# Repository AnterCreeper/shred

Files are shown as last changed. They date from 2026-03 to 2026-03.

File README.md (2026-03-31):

# SHRED: (S)ystem for (H)igh-performance (R)eal-time (E)lectric guitar (D)igital effects

If you have any questions, feel free to open Issues & PRs.

**WARNING! This project has not been fully tested in long-term production environments and is provided without warranty of any kind. Use at your own risk!**

## License

This project is licensed under the LGPL-2.1-or-later license.

**DO NOT** download or clone this project until you have read and agreed to the LICENSE.

## TODO

1. plug subboard designs
2. FPGA RTL integration
3. controller firmware

## Overview

This project implements an audio system for electric guitars and consists of essential components, including the hardware (core and plug) with Gerber files and schematics, digital logic designs, mechanical designs for the pickguard, and firmware for a low-power microcontroller that provides HMI and system controls.

The TFT screen is not included, which is from Waveshare ([Click here](https://www.waveshare.net/wiki/1.9inch_LCD_Module)) and would be easy to obtain.

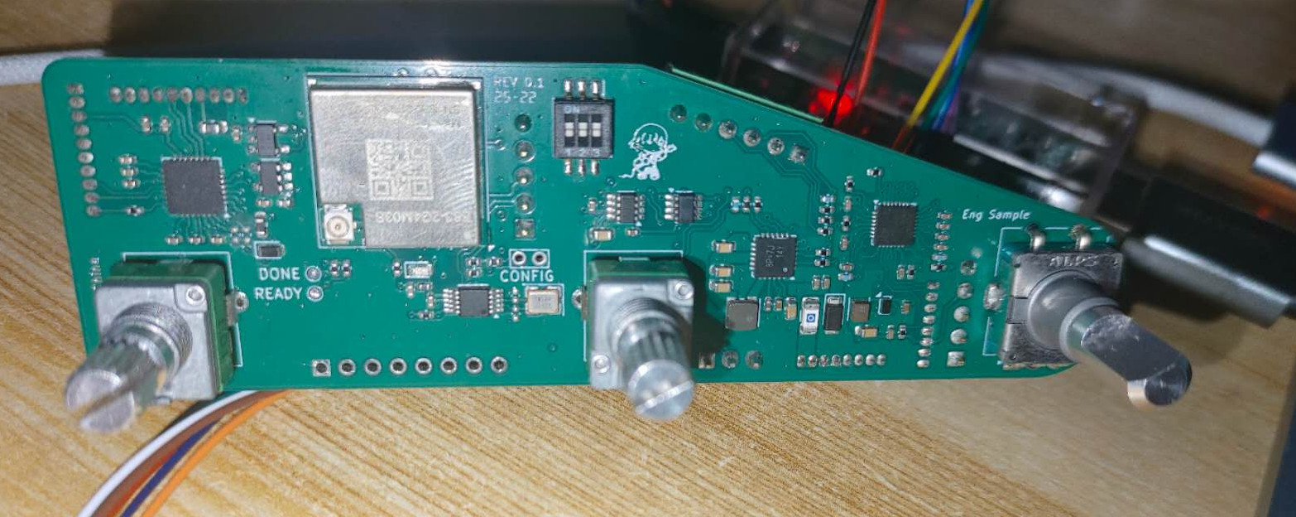
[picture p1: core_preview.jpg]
PCB Preview Picture


## Functions

- Audio Record & Playback (SD Card)
- Audio Mixer
- USB Audio Input and Output
- Wireless BLE Real-time Audio Monitor
- Audio Effects (chorus, distortion, EQ...)

## Directory

### Core

This directory contains PCB designs (KiCad) for the main board, which implements most functions. It includes battery management (TI `BQ25601` charger with `TPD2S300` for Type-C PD high-voltage fast charging, and TI `BQ27720` energy gauge), system microcontroller (WCH `CH32X035`), FPGA unit (Gowin `Tang Primer 25K`), and the audio subsystem (ADI/Maxim `MAX9850` I2S DAC + onsemi `FAN3852` AFE+ADC to PDM, and Skyworks/Silicon Labs `Si5351` for clock generation). In addition, this system includes a BLE module (Nordic `nRF5340`) to provide ultra-low latency LE Audio streaming capability.

The power rails are carefully designed to provide long battery life. The system employs several load switches (MPS `MP5095` and Diodes `AP2151`) and ultra-low quiescent current regulators (TI `TPS62743` and `TPS7A20`), allowing specific components (keys and screen, audio system, flash storage, Bluetooth) to be shut down or set to low-power states.

The dual magnetic pickups are connected via IPEX-4 (some soldering work is required to modify the connection wires), which provides low-noise, pure raw signals.

### Plug

This directory contains PCB designs (KiCad) for the plug subboard, which includes an `audio jack`, `microSD slot`, `USB-C receptacle`, `charge indicator`, and `ambient light sensor`.

### RTL

This directory contains the audio processing logic:
- Core processor
- Audio synthesizer
- FLAC encoder & decoder
- Audio I/O interface
- USB device interface
- I2C device interface
- SD host controller interface

### Controller

This directory contains the system controller firmware, which sets up every device, monitors system states, renders the HMI, and reacts to user input events.

### LE-Audio

This directory contains the BLE module firmware subproject from a separate repository. It scans, connects, and pairs with earbuds, and then performs real-time audio streaming (LC3). This module acts as a peripheral to the system controller, communicating via a standard AT interface over UART.

### Others

Miscellaneous files under the root:
- `pickguard.dxf`: Pickguard CAD designs.
- `logo.jped`: Logo of `SHRED`, generated by Google NanoBanana 2.
- `logo.prompt`: Prompt of AI gen.

## Usage

**This section is W.I.P. and will be completed in the future.**

Star History Chart (https://www.star-history.com/#antercreeper/shred&type=date&legend=top-left)

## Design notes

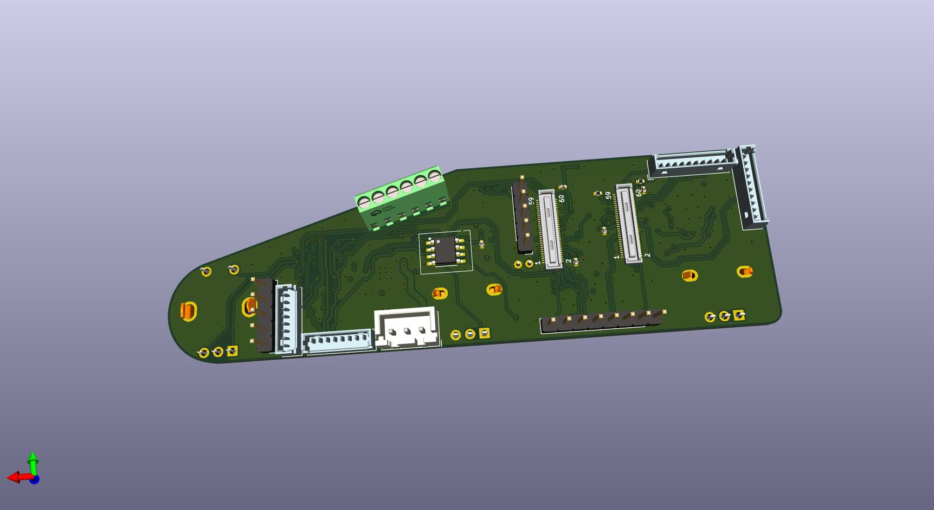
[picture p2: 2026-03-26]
core/audio_lab_back.jpg

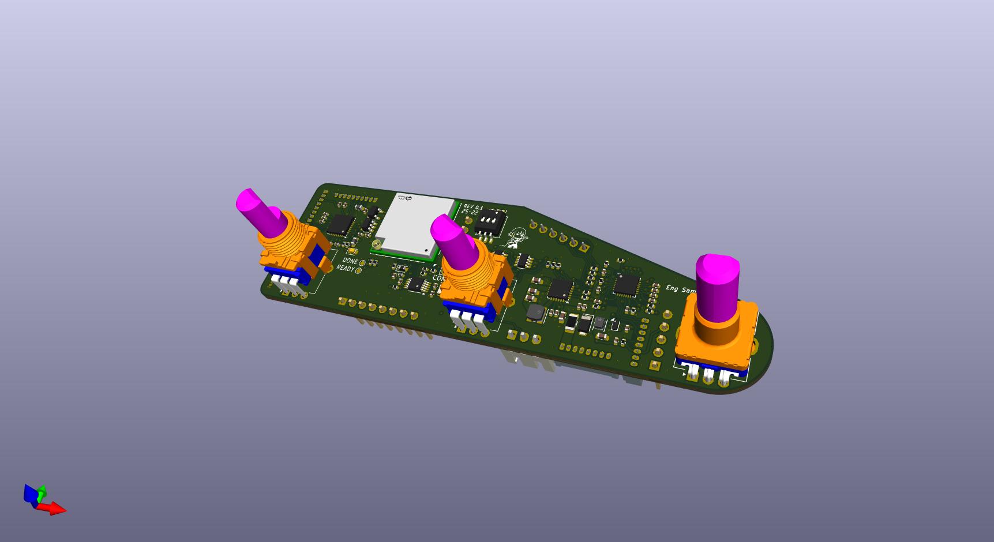
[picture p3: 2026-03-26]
core/audio_lab_front.jpg

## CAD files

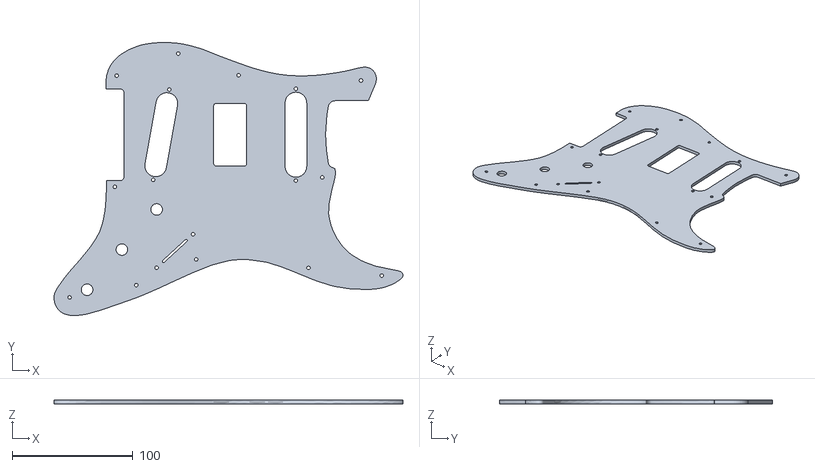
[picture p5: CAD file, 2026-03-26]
pickguard.stl
289.1 x 226.3 x 3.00

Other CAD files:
pickguard.dxf

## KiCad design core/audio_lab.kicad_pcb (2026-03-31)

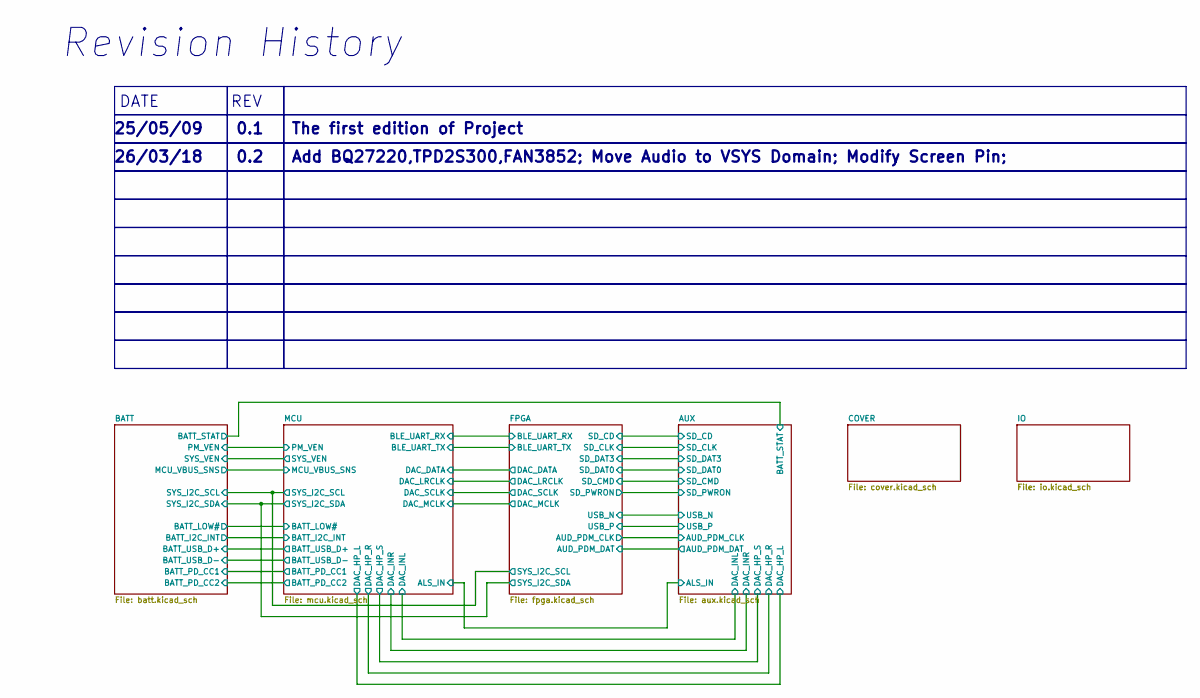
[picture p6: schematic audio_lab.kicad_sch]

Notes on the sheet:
Revision History
REV
0.2
Add BQ27220,TPD2S300,FAN3852; Move Audio to VSYS Domain; Modify Screen Pin;
0.1
25/05/09
The first edition of Project
DATE
26/03/18

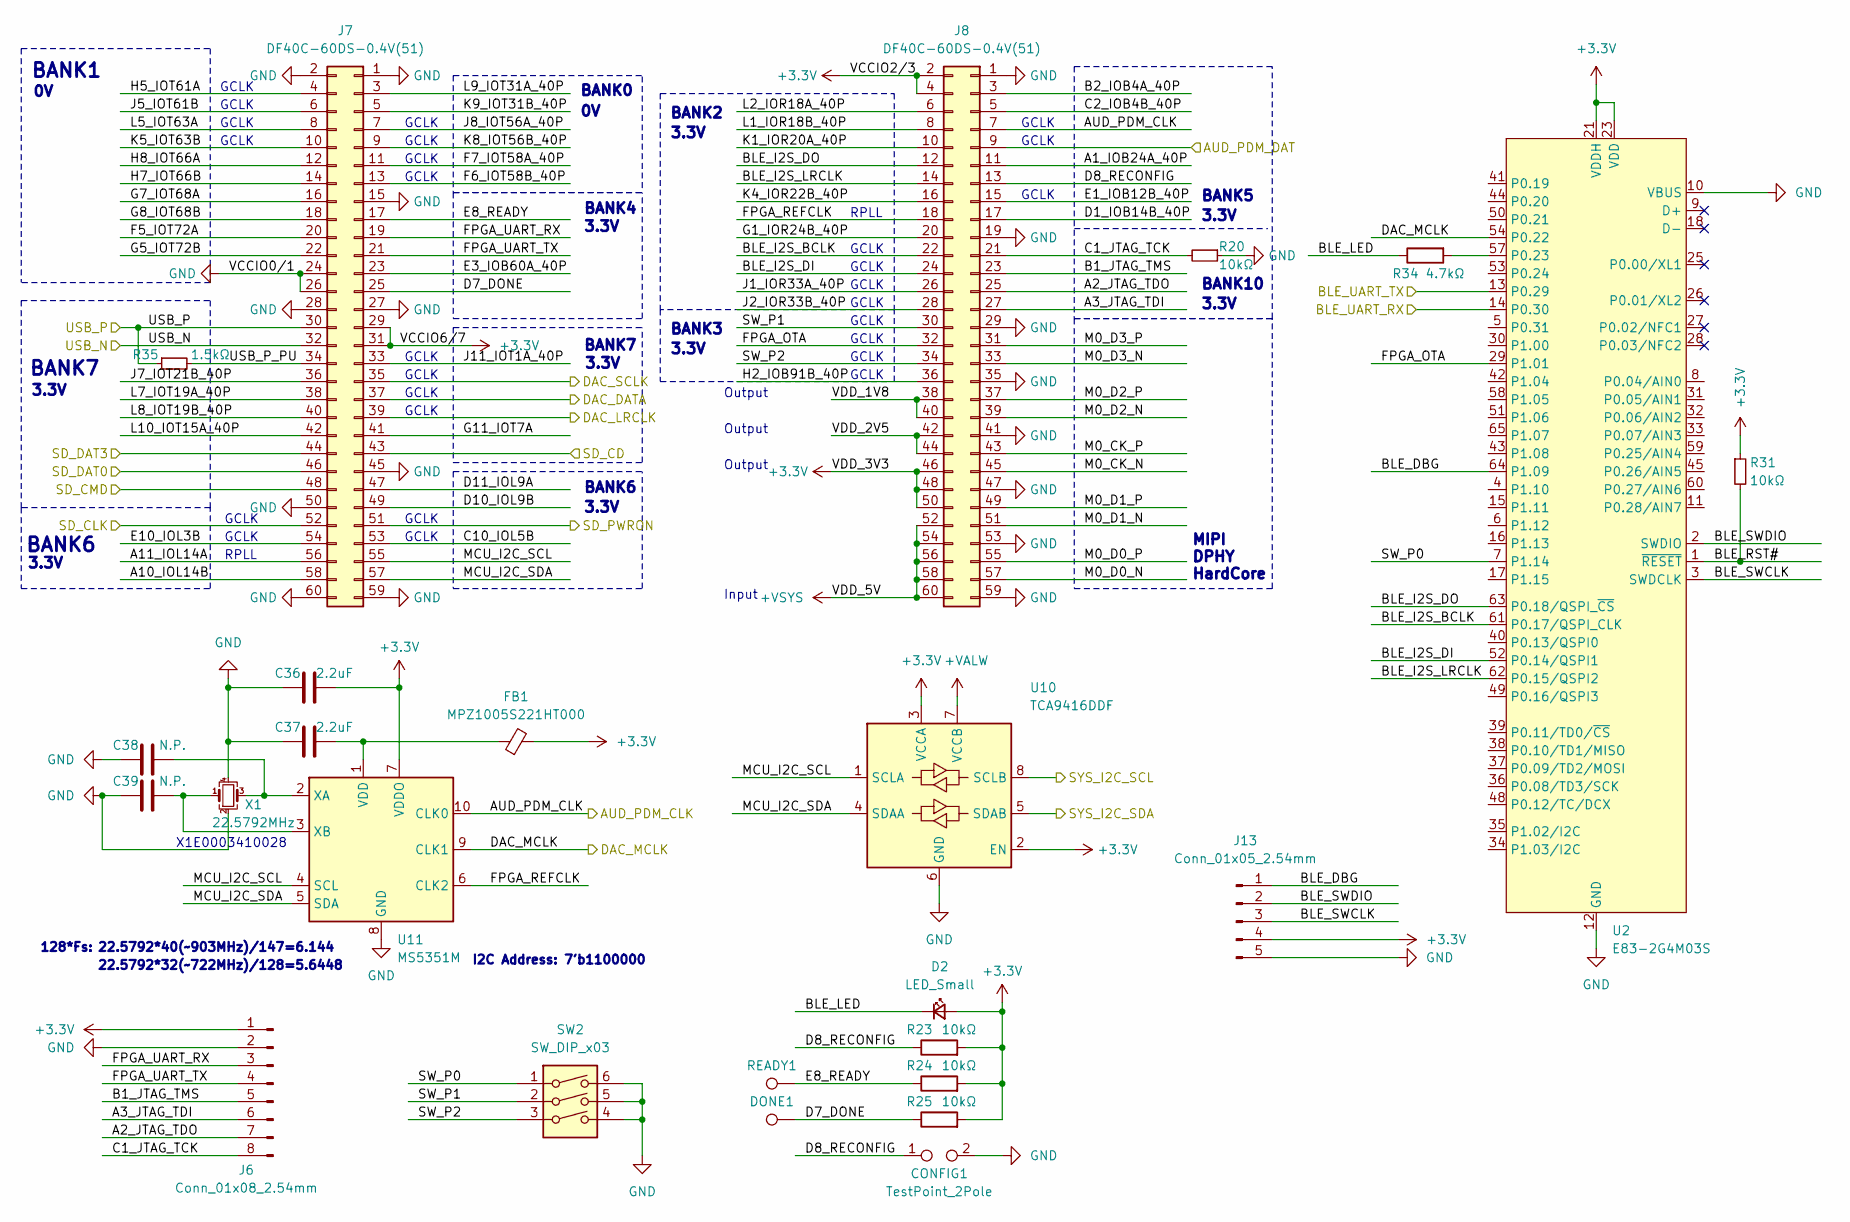
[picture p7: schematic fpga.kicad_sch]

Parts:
C36, C37: 2.2uF; C_0402_1005Metric
C38, C39: N.P.; C_0402_1005Metric
CONFIG1: TestPoint_2Pole; TestPoint_Bridge_Pitch2.0mm_Drill0.7mm
D2: LED_Small; D_0603_1608Metric
DONE1: TestPoint; TestPoint_Pad_D1.0mm
FB1: MPZ1005S221HT000; L_0402_1005Metric
J6: Conn_01x08_2.54mm; PinHeader_1x08_P2.54mm_Vertical
J7, J8: DF40C-60DS-0.4V(51); BTB-DF40C-60DS-0.4V(51)
J13: Conn_01x05_2.54mm; PinHeader_1x05_P2.54mm_Vertical
R20, R23, R24, R25, R31: 10kΩ; R_0402_1005Metric
R34: 4.7kΩ; R_0402_1005Metric
R35: 1.5kΩ; R_0402_1005Metric
READY1: TestPoint; TestPoint_Pad_D1.0mm
SW2: SW_DIP_x03; SW_DIP_SPSTx03_Slide_KingTek_DSHP03TS_W7.62mm_P1.27mm
U2: E83-2G4M03S; E83-2G4M03S_16x16mm_LGA; LCSC C5333991
U10: TCA9416DDF; TSOT-23-8
U11: MS5351M; MSOP-10_3x3mm_P0.5mm
X1: 22.5792MHz; Crystal_SMD_3225-4Pin_3.2x2.5mm

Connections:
+3.3V: C36.2, D2.2 (A), FB1.2, J6.1, J7.29, J7.31, J8.2, J8.4, J8.46, J8.48, J8.50, J13.4, R23.2, R24.2, R25.2, R31.1, U2.21 (VDDH), U2.23 (VDD), U10.2 (EN), U10.3 (VCCA), U11.7 (VDDO); also elsewhere on the board
+VALW: U10.7 (VCCB); also elsewhere on the board
+VSYS: J8.52, J8.54, J8.56, J8.58, J8.60; also elsewhere on the board
/AUX/AUD_PDM_DAT: J8.9; also elsewhere on the board
/AUX/SD_CD: J7.43; also elsewhere on the board
/AUX/SD_CLK: J7.52; also elsewhere on the board
/AUX/SD_CMD: J7.48; also elsewhere on the board
/AUX/SD_DAT0: J7.46; also elsewhere on the board
/AUX/SD_DAT3: J7.44; also elsewhere on the board
/AUX/SD_PWRON: J7.51; also elsewhere on the board
/BATT/SYS_I2C_SCL: U10.8 (SCLB); also elsewhere on the board
/BATT/SYS_I2C_SDA: U10.5 (SDAB); also elsewhere on the board
/FPGA/A1_IOB24A_40P: J8.11
/FPGA/A2_JTAG_TDO: J6.7, J8.25
/FPGA/A3_JTAG_TDI: J6.6, J8.27
/FPGA/A10_IOL14B: J7.58
/FPGA/A11_IOL14A: J7.56
/FPGA/AUD_PDM_CLK: J8.7, U11.10 (CLK0); also elsewhere on the board
/FPGA/B1_JTAG_TMS: J6.5, J8.23
/FPGA/B2_IOB4A_40P: J8.3
/FPGA/BLE_DBG: J13.1, U2.64 (P1.09)
/FPGA/BLE_I2S_BCLK: J8.22, U2.61 (P0.17/QSPI_CLK)
/FPGA/BLE_I2S_DI: J8.24, U2.52 (P0.14/QSPI1)
/FPGA/BLE_I2S_DO: J8.12, U2.63 (P0.18/QSPI_~CS)
/FPGA/BLE_I2S_LRCLK: J8.14, U2.62 (P0.15/QSPI2)
/FPGA/BLE_LED: D2.1 (K), R34.1
/FPGA/BLE_RST#: R31.2, U2.1 (~RESET)
/FPGA/BLE_SWCLK: J13.3, U2.3 (SWDCLK)
/FPGA/BLE_SWDIO: J13.2, U2.2 (SWDIO)
/FPGA/BLE_UART_RX: U2.14 (P0.30); also elsewhere on the board
/FPGA/BLE_UART_TX: U2.13 (P0.29); also elsewhere on the board
/FPGA/C1_JTAG_TCK: J6.8, J8.21, R20.2
/FPGA/C2_IOB4B_40P: J8.5
/FPGA/C10_IOL5B: J7.53
/FPGA/D1_IOB14B_40P: J8.17
/FPGA/D7_DONE: DONE1.1, J7.25, R25.1; also elsewhere on the board
/FPGA/D8_RECONFIG: CONFIG1.1, J8.13, R23.1; also elsewhere on the board
/FPGA/D10_IOL9B: J7.49
/FPGA/D11_IOL9A: J7.47
/FPGA/DAC_DATA: J7.37; also elsewhere on the board
/FPGA/DAC_LRCLK: J7.39; also elsewhere on the board
/FPGA/DAC_MCLK: U2.54 (P0.22), U11.9 (CLK1); also elsewhere on the board
/FPGA/DAC_SCLK: J7.35; also elsewhere on the board
/FPGA/E1_IOB12B_40P: J8.15
/FPGA/E3_IOB60A_40P: J7.23
/FPGA/E8_READY: J7.17, R24.1, READY1.1; also elsewhere on the board
/FPGA/E10_IOL3B: J7.54
/FPGA/F5_IOT72A: J7.20
/FPGA/F6_IOT58B_40P: J7.13
/FPGA/F7_IOT58A_40P: J7.11
/FPGA/FPGA_OTA: J8.32, U2.29 (P1.01)
/FPGA/FPGA_REFCLK: J8.18, U11.6 (CLK2)
/FPGA/FPGA_UART_RX: J6.3, J7.19
/FPGA/FPGA_UART_TX: J6.4, J7.21
/FPGA/G1_IOR24B_40P: J8.20
/FPGA/G5_IOT72B: J7.22
/FPGA/G7_IOT68A: J7.16
/FPGA/G8_IOT68B: J7.18
/FPGA/G11_IOT7A: J7.41
/FPGA/H2_IOB91B_40P: J8.36
/FPGA/H5_IOT61A: J7.4
/FPGA/H7_IOT66B: J7.14
/FPGA/H8_IOT66A: J7.12
/FPGA/J1_IOR33A_40P: J8.26
/FPGA/J2_IOR33B_40P: J8.28
/FPGA/J5_IOT61B: J7.6
/FPGA/J7_IOT21B_40P: J7.36
/FPGA/J8_IOT56A_40P: J7.7
/FPGA/J11_IOT1A_40P: J7.33
/FPGA/K1_IOR20A_40P: J8.10
/FPGA/K4_IOR22B_40P: J8.16
/FPGA/K5_IOT63B: J7.10
/FPGA/K8_IOT56B_40P: J7.9
/FPGA/K9_IOT31B_40P: J7.5
/FPGA/L1_IOR18B_40P: J8.8
/FPGA/L2_IOR18A_40P: J8.6
/FPGA/L5_IOT63A: J7.8
/FPGA/L7_IOT19A_40P: J7.38
/FPGA/L8_IOT19B_40P: J7.40
/FPGA/L9_IOT31A_40P: J7.3
/FPGA/L10_IOT15A_40P: J7.42
/FPGA/M0_CK_N: J8.45
/FPGA/M0_CK_P: J8.43
/FPGA/M0_D0_N: J8.57
/FPGA/M0_D0_P: J8.55
/FPGA/M0_D1_N: J8.51
/FPGA/M0_D1_P: J8.49
/FPGA/M0_D2_N: J8.39
/FPGA/M0_D2_P: J8.37
/FPGA/M0_D3_N: J8.33
/FPGA/M0_D3_P: J8.31
/FPGA/MCU_I2C_SCL: J7.55, U10.1 (SCLA), U11.4 (SCL)
/FPGA/MCU_I2C_SDA: J7.57, U10.4 (SDAA), U11.5 (SDA)
/FPGA/SW_P0: SW2.1, U2.7 (P1.14)
/FPGA/SW_P1: J8.30, SW2.2
/FPGA/SW_P2: J8.34, SW2.3
/FPGA/USB_N: J7.32; also elsewhere on the board
/FPGA/USB_P: J7.30, R35.1; also elsewhere on the board
/FPGA/USB_P_PU: J7.34, R35.2
/FPGA/VDD_1V8: J8.38, J8.40
/FPGA/VDD_2V5: J8.42, J8.44
GND: C36.1, C37.1, C38.1, C39.1, CONFIG1.2, J6.2, J7.1, J7.2, J7.15, J7.24, J7.26, J7.27, J7.28, J7.45, J7.50, J7.59, J7.60, J8.1, J8.19, J8.29, J8.35, J8.41, J8.47, J8.53, J8.59, J13.5, R20.1, SW2.4, SW2.5, SW2.6, U2.10 (VBUS), U2.12 (GND), U2.19 (GND), U2.20 (GND), U2.22 (GND), U2.24 (GND), U2.46 (GND), U2.47 (GND), U2.55 (GND), U2.56 (GND), U10.6 (GND), U11.8 (GND), X1.2, X1.4; also elsewhere on the board
unnamed: R34.2, U2.57 (P0.23)
unnamed: C37.2, FB1.1, U11.1 (VDD)
unnamed: C38.2, U11.2 (XA), X1.3
unnamed: C39.2, U11.3 (XB), X1.1

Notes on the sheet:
GCLK
BANK6
RPLL
BANK2
22.5792*32(~722MHz)/128=5.6448
3.3V
BANK10
MIPI DPHY HardCore
BANK4
BANK5
X1E0003410028
Input
Output
BANK7
I2C Address: 7'b1100000
128*Fs:
BANK1
22.5792*40(~903MHz)/147=6.144
BANK3
BANK0

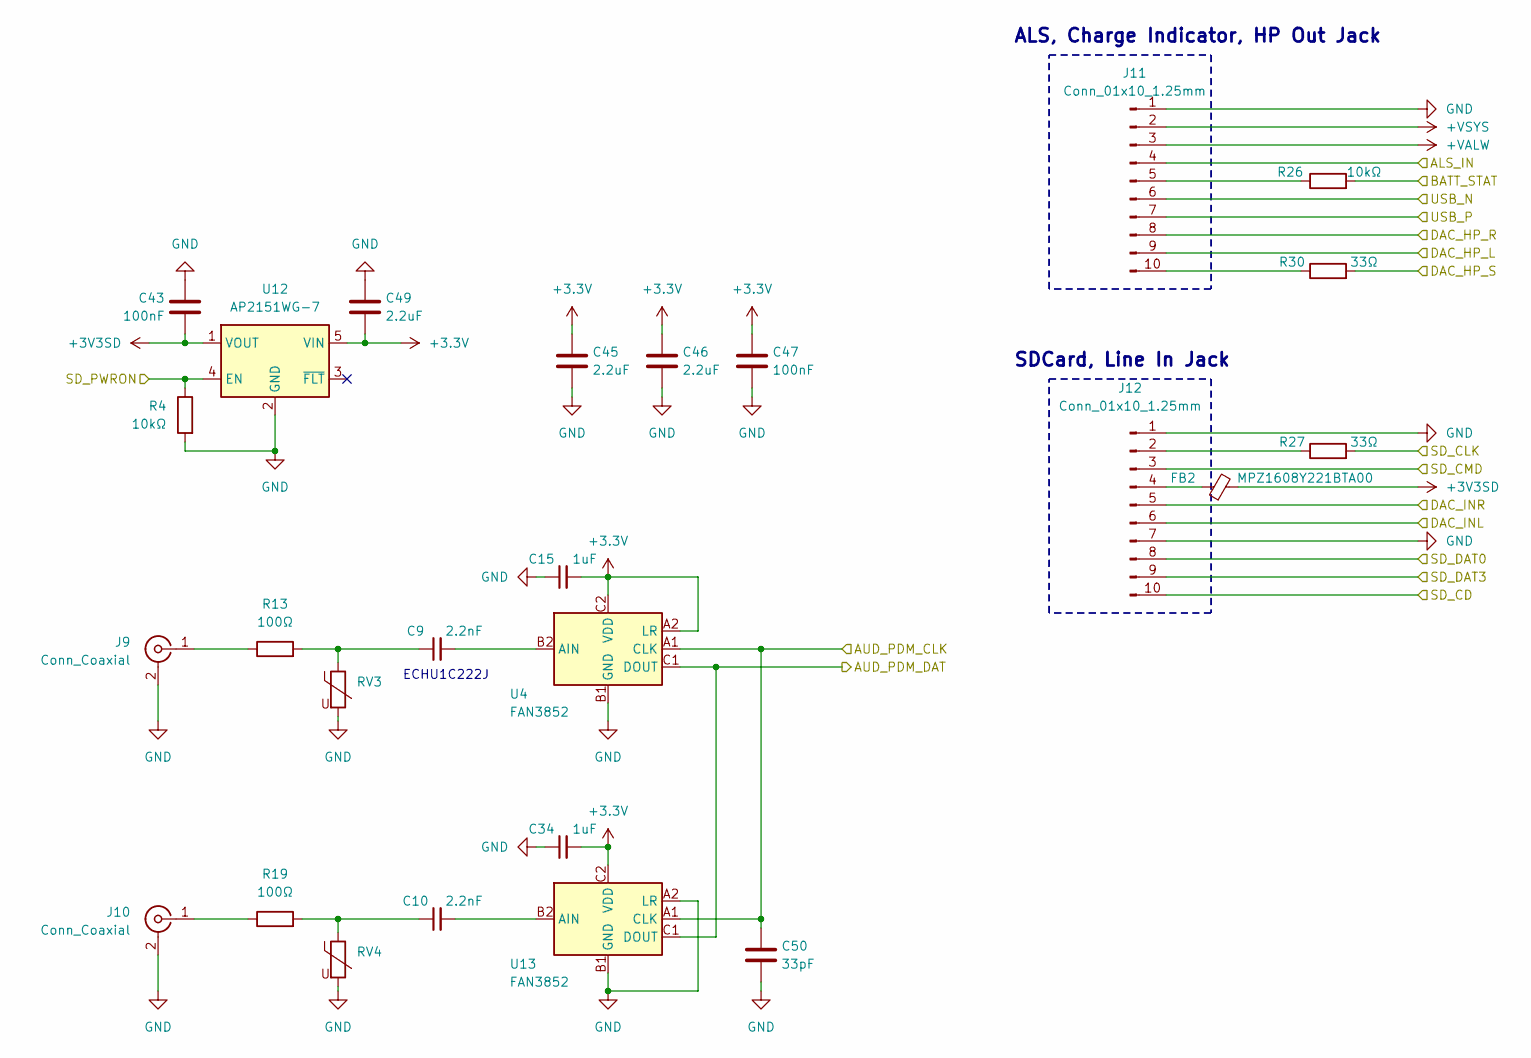
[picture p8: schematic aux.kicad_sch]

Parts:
C9, C10: 2.2nF; C_0603_1608Metric
C15, C34: 1uF; C_0402_1005Metric
C43, C47: 100nF; C_0402_1005Metric
C45, C46, C49: 2.2uF; C_0402_1005Metric
C50: 33pF; C_0402_1005Metric
FB2: MPZ1608Y221BTA00; L_0603_1608Metric
J9, J10: Conn_Coaxial; IPEX_20449-001E-03
J11, J12: Conn_01x10_1.25mm; Molex_PicoBlade_53047-1010_1x10_P1.25mm_Vertical
R4, R26: 10kΩ; R_0402_1005Metric
R13, R19: 100Ω; R_0402_1005Metric
R27, R30: 33Ω; R_0402_1005Metric
RV3, RV4: Varistor; R_0402_1005Metric
U4, U13: FAN3852; Texas_DSBGA-6_0.855x1.255mm_Layout2x3_P0.4mm_LevelC
U12: AP2151WG-7; SOT-23-5

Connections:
+3.3V: C15.2, C34.2, C45.1, C46.1, C47.1, C49.2, U4.A2 (LR), U4.C2 (VDD), U12.5 (VIN), U13.C2 (VDD); also elsewhere on the board
+3V3SD: C43.2, FB2.2, U12.1 (VOUT)
+VALW: J11.3; also elsewhere on the board
+VSYS: J11.2; also elsewhere on the board
/AUX/ALS_IN: J11.4; also elsewhere on the board
/AUX/AUD_PDM_DAT: U4.C1 (DOUT), U13.C1 (DOUT); also elsewhere on the board
/AUX/BATT_STAT: R26.2; also elsewhere on the board
/AUX/DAC_HP_L: J11.9; also elsewhere on the board
/AUX/DAC_HP_R: J11.8; also elsewhere on the board
/AUX/DAC_HP_S: R30.2; also elsewhere on the board
/AUX/DAC_INL: J12.6; also elsewhere on the board
/AUX/DAC_INR: J12.5; also elsewhere on the board
/AUX/SD_CD: J12.10; also elsewhere on the board
/AUX/SD_CLK: R27.2; also elsewhere on the board
/AUX/SD_CMD: J12.3; also elsewhere on the board
/AUX/SD_DAT0: J12.8; also elsewhere on the board
/AUX/SD_DAT3: J12.9; also elsewhere on the board
/AUX/SD_PWRON: R4.1, U12.4 (EN); also elsewhere on the board
/FPGA/AUD_PDM_CLK: C50.1, U4.A1 (CLK), U13.A1 (CLK); also elsewhere on the board
/FPGA/USB_N: J11.6; also elsewhere on the board
/FPGA/USB_P: J11.7; also elsewhere on the board
GND: C15.1, C34.1, C43.1, C45.2, C46.2, C47.2, C49.1, C50.2, J9.2 (Ext), J10.2 (Ext), J11.1, J12.1, J12.7, R4.2, RV3.2, RV4.2, U4.B1 (GND), U12.2 (GND), U13.A2 (LR), U13.B1 (GND); also elsewhere on the board
unnamed: C9.1, R13.2, RV3.1
unnamed: C10.1, R19.2, RV4.1
unnamed: J9.1 (In), R13.1
unnamed: J10.1 (In), R19.1
unnamed: J11.5, R26.1
unnamed: J11.10, R30.1
unnamed: J12.2, R27.1
unnamed: FB2.1, J12.4
unnamed: C9.2, U4.B2 (AIN)
unnamed: C10.2, U13.B2 (AIN)

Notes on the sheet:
ECHU1C222J
SDCard, Line In Jack
ALS, Charge Indicator, HP Out Jack

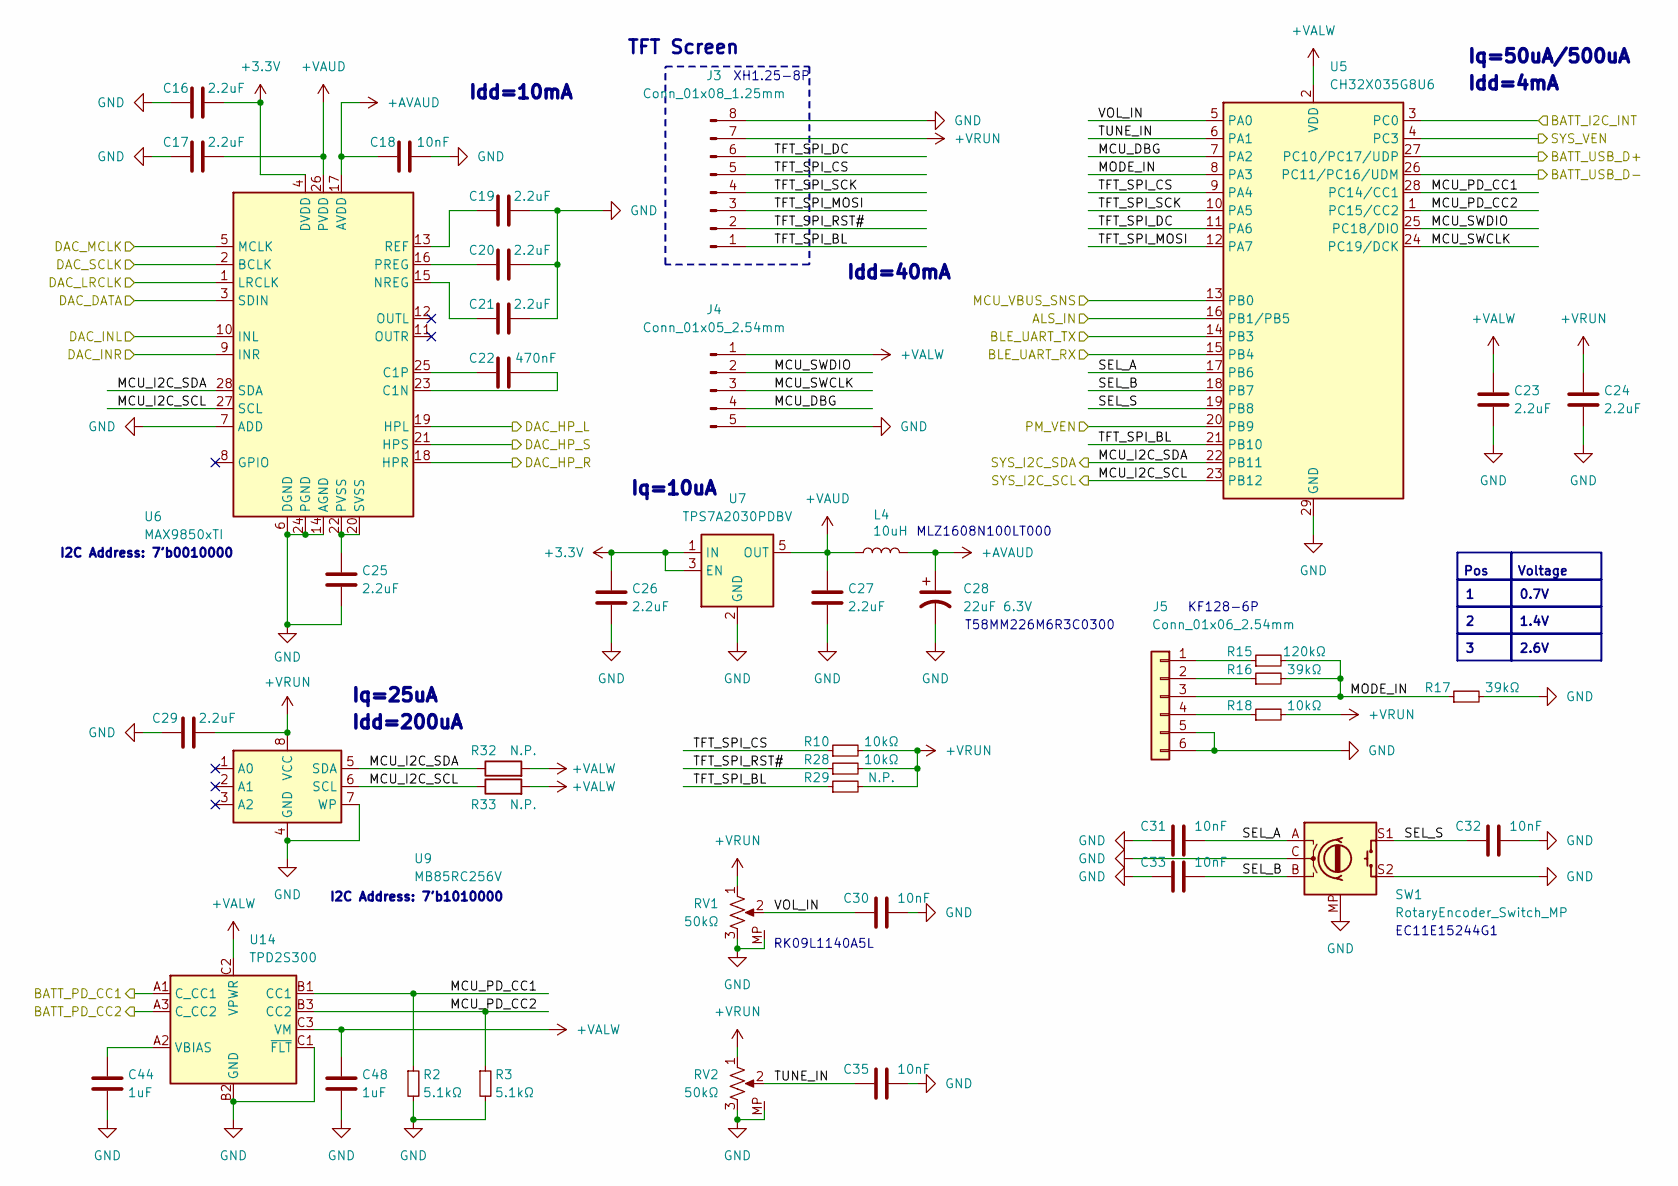
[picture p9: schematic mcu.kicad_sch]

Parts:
C16, C17, C19, C20, C21, C23, C24, C25, C26, C27, C29: 2.2uF; C_0402_1005Metric
C18, C30, C31, C32, C33, C35: 10nF; C_0402_1005Metric
C22: 470nF; C_0402_1005Metric
C28: 22uF 6.3V; CP_EIA-1608-08_AVX-J
C44, C48: 1uF; C_0402_1005Metric
J3: Conn_01x08_1.25mm; Molex_PicoBlade_53047-0810_1x08_P1.25mm_Vertical
J4: Conn_01x05_2.54mm; PinHeader_1x05_P2.54mm_Vertical
J5: Conn_01x06_2.54mm; PinSocket_1x06_P2.54mm_Vertical
L4: 10uH; L_0603_1608Metric
R2, R3: 5.1kΩ; R_0402_1005Metric
R10, R18, R28: 10kΩ; R_0402_1005Metric
R15: 120kΩ; R_0402_1005Metric
R16, R17: 39kΩ; R_0402_1005Metric
R29, R32, R33: N.P.; R_0402_1005Metric
RV1, RV2: 50kΩ; Potentiometer_Alpha_RD901F-40-00D_Single_Vertical
SW1: RotaryEncoder_Switch_MP; RotaryEncoder_Favor_FEC11_Vertical_H15mm
U5: CH32X035G8U6; QFN-28-1EP_4x4mm_P0.4mm_EP2.7x2.7mm
U6: MAX9850xTI; TQFN-28-1EP_5x5mm_P0.5mm_EP3.25x3.25mm_ThermalVias
U7: TPS7A2030PDBV; SOT-23-5
U9: MB85RC256V; SOIC-8_3.9x4.9mm_P1.27mm
U14: TPD2S300; Texas_DSBGA-9_1.36x1.36mm_Layout3x3_P0.4mm

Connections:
+3.3V: C16.2, C26.1, U6.4 (DVDD), U7.1 (IN), U7.3 (EN); also elsewhere on the board
+AVAUD: C18.1, C28.1, L4.2, U6.17 (AVDD)
+VALW: C23.1, C48.1, J4.1, R32.2, R33.2, U5.2 (VDD), U14.C2 (VPWR), U14.C3 (VM); also elsewhere on the board
+VAUD: C17.2, C27.1, L4.1, U6.26 (PVDD), U7.5 (OUT)
+VRUN: C24.1, C29.2, J3.7, R10.2, R18.2, R28.2, R29.2, RV1.1, RV2.1, U9.8 (VCC); also elsewhere on the board
/AUX/ALS_IN: U5.16 (PB1/PB5); also elsewhere on the board
/AUX/DAC_HP_L: U6.19 (HPL); also elsewhere on the board
/AUX/DAC_HP_R: U6.18 (HPR); also elsewhere on the board
/AUX/DAC_HP_S: U6.21 (HPS); also elsewhere on the board
/AUX/DAC_INL: U6.10 (INL); also elsewhere on the board
/AUX/DAC_INR: U6.9 (INR); also elsewhere on the board
/BATT/BATT_I2C_INT: U5.3 (PC0); also elsewhere on the board
/BATT/BATT_PD_CC1: U14.A1 (C_CC1); also elsewhere on the board
/BATT/BATT_PD_CC2: U14.A3 (C_CC2); also elsewhere on the board
/BATT/BATT_USB_D+: U5.27 (PC10/PC17/UDP); also elsewhere on the board
/BATT/BATT_USB_D-: U5.26 (PC11/PC16/UDM); also elsewhere on the board
/BATT/MCU_VBUS_SNS: U5.13 (PB0); also elsewhere on the board
/BATT/PM_VEN: U5.20 (PB9); also elsewhere on the board
/BATT/SYS_I2C_SCL: R33.1, U5.23 (PB12), U6.27 (SCL), U9.6 (SCL); also elsewhere on the board
/BATT/SYS_I2C_SDA: R32.1, U5.22 (PB11), U6.28 (SDA), U9.5 (SDA); also elsewhere on the board
/BATT/SYS_VEN: U5.4 (PC3); also elsewhere on the board
/FPGA/BLE_UART_RX: U5.15 (PB4); also elsewhere on the board
/FPGA/BLE_UART_TX: U5.14 (PB3); also elsewhere on the board
/FPGA/DAC_DATA: U6.3 (SDIN); also elsewhere on the board
/FPGA/DAC_LRCLK: U6.1 (LRCLK); also elsewhere on the board
/FPGA/DAC_MCLK: U6.5 (MCLK); also elsewhere on the board
/FPGA/DAC_SCLK: U6.2 (BCLK); also elsewhere on the board
/MCU/MCU_DBG: J4.4, U5.7 (PA2)
/MCU/MCU_PD_CC1: R2.1, U5.28 (PC14/CC1), U14.B1 (CC1)
/MCU/MCU_PD_CC2: R3.1, U5.1 (PC15/CC2), U14.B3 (CC2)
/MCU/MCU_SWCLK: J4.3, U5.24 (PC19/DCK)
/MCU/MCU_SWDIO: J4.2, U5.25 (PC18/DIO)
/MCU/MODE_IN: J5.3, R15.2, R16.2, R17.1, U5.8 (PA3)
/MCU/SEL_A: C31.2, SW1.A, U5.17 (PB6)
/MCU/SEL_B: C33.2, SW1.B, U5.18 (PB7)
/MCU/SEL_S: C32.1, SW1.S1, U5.19 (PB8)
/MCU/TFT_SPI_BL: J3.1, R29.1, U5.21 (PB10)
/MCU/TFT_SPI_CS: J3.5, R10.1, U5.9 (PA4)
/MCU/TFT_SPI_DC: J3.6, U5.11 (PA6)
/MCU/TFT_SPI_MOSI: J3.3, U5.12 (PA7)
/MCU/TFT_SPI_RST#: J3.2, R28.1
/MCU/TFT_SPI_SCK: J3.4, U5.10 (PA5)
/MCU/TUNE_IN: C35.1, RV2.2, U5.6 (PA1)
/MCU/VOL_IN: C30.1, RV1.2, U5.5 (PA0)
GND: C16.1, C17.1, C18.2, C19.2, C20.2, C21.2, C23.2, C24.2, C25.2, C26.2, C27.2, C28.2, C29.1, C30.2, C31.1, C32.2, C33.1, C35.2, C44.2, C48.2, J3.8, J4.5, J5.5, J5.6, R2.2, R3.2, R17.2, RV1.3, RV1.MP, RV2.3, RV2.MP, SW1.C, SW1.MP, SW1.S2, U5.29 (GND), U6.6 (DGND), U6.7 (ADD), U6.14 (AGND), U6.24 (PGND), U6.29 (AGND), U7.2 (GND), U9.4 (GND), U9.7 (WP), U14.B2 (GND), U14.C1 (~FLT); also elsewhere on the board
unnamed: J5.1, R15.1
unnamed: J5.2, R16.1
unnamed: J5.4, R18.1
unnamed: C22.2, U6.23 (C1N)
unnamed: C22.1, U6.25 (C1P)
unnamed: C21.1, U6.15 (NREG)
unnamed: C20.1, U6.16 (PREG)
unnamed: C25.1, U6.20 (SVSS), U6.22 (PVSS)
unnamed: C19.1, U6.13 (REF)
unnamed: C44.1, U14.A2 (VBIAS)

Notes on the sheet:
T58MM226M6R3C0300
Idd=4mA
TFT Screen
Pos
Iq=50uA/500uA
XH1.25-8P
RK09L1140A5L
MLZ1608N100LT000
0.7V
1.4V
Idd=200uA
Idd=10mA
Iq=10uA
Iq=25uA
2.6V
I2C Address: 7'b1010000
Voltage
I2C Address: 7'b0010000
Idd=40mA
KF128-6P
EC11E15244G1

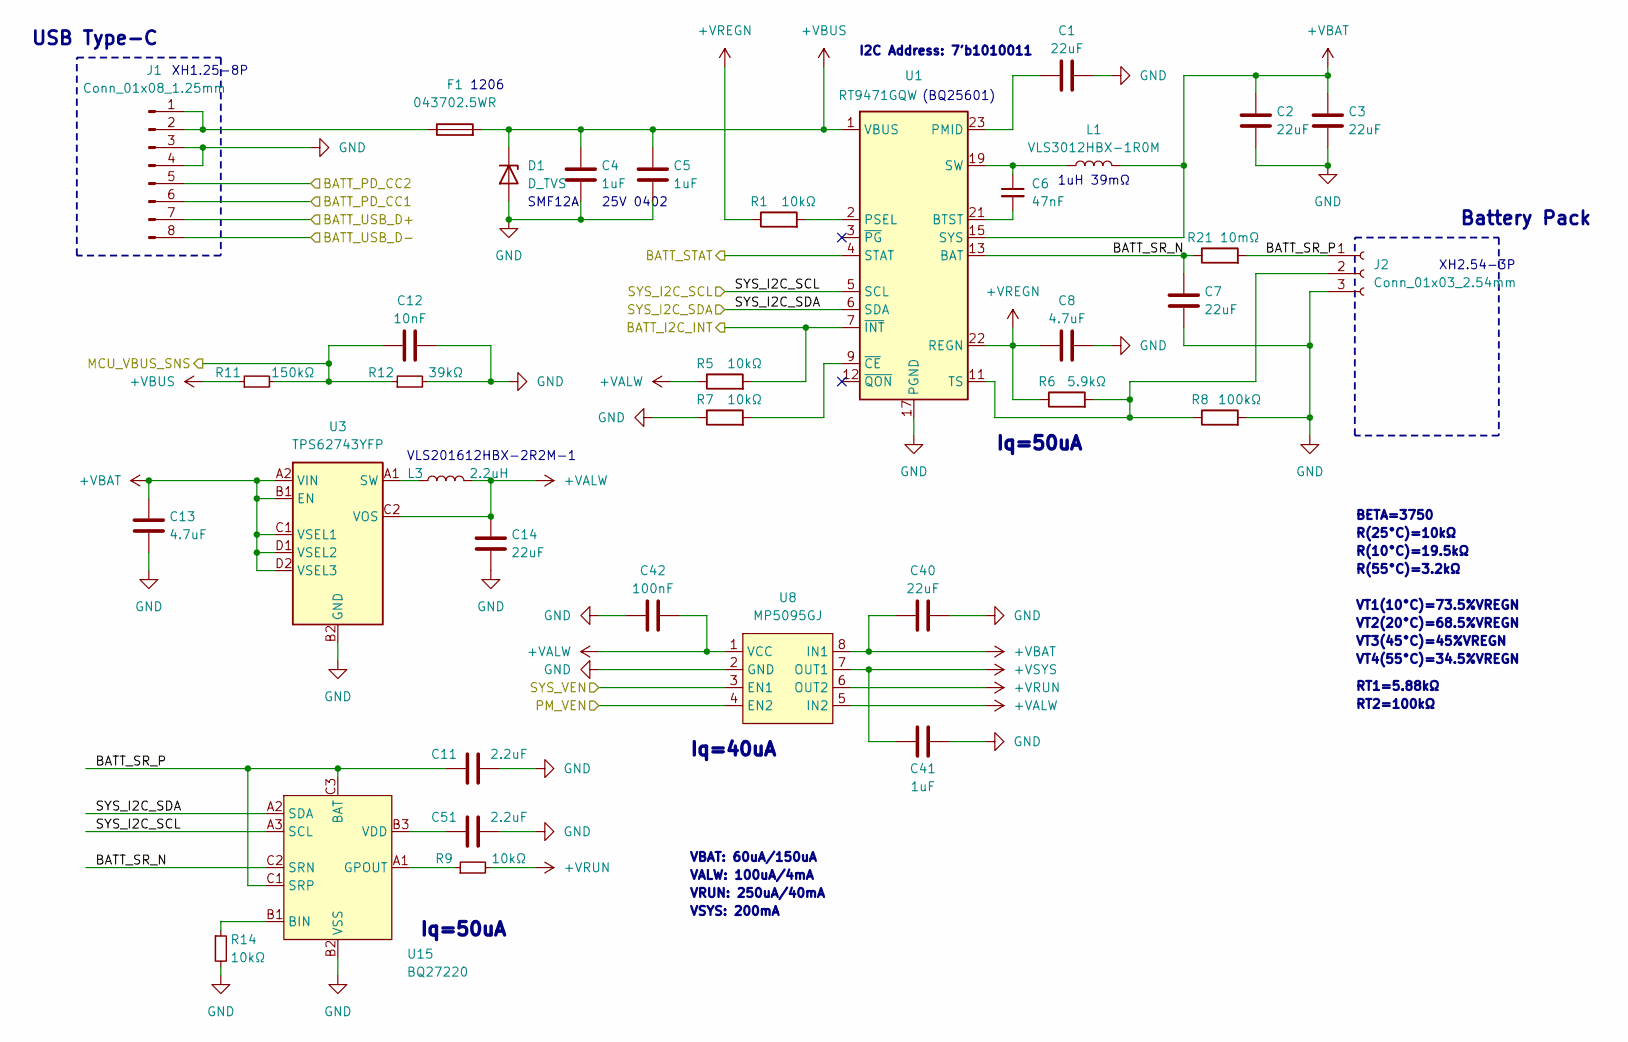
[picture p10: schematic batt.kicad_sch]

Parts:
C1, C2, C3, C7, C14, C40: 22uF; C_0603_1608Metric
C4, C5, C41: 1uF; C_0402_1005Metric
C6: 47nF; C_0402_1005Metric
C8, C13: 4.7uF; C_0402_1005Metric
C11, C51: 2.2uF; C_0402_1005Metric
C12: 10nF; C_0402_1005Metric
C42: 100nF; C_0402_1005Metric
D1: D_TVS; D_PowerDI-123
F1: 043702.5WR; Fuse_1206_3216Metric
J1: Conn_01x08_1.25mm; Molex_PicoBlade_53047-0810_1x08_P1.25mm_Vertical
J2: Conn_01x03_2.54mm; JST_XH_B3B-XH-A_1x03_P2.50mm_Vertical
L1: VLS3012HBX-1R0M; L_TDK_VLS3012HBX
L3: 2.2uH; L_Murata_DFE201610P
R1, R5, R7, R9, R14: 10kΩ; R_0402_1005Metric
R6: 5.9kΩ; R_0402_1005Metric
R8: 100kΩ; R_0402_1005Metric
R11: 150kΩ; R_0402_1005Metric
R12: 39kΩ; R_0402_1005Metric
R21: 10mΩ; R_1206_3216Metric
U1: RT9471GQW; RICKTEK_WQFN-24-1EP_4x4mm_P0.5mm_EP2.6x2.6mm_ThermalVias
U3: TPS62743YFP; Texas_DSBGA-8_0.86x1.56mm_Layout2x4_P0.4mm
U8: MP5095GJ; TSOT-23-8
U15: BQ27220; Texas_DSBGA-9_1.62x1.58mm_Layout3x3_P0.5mm

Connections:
+VALW: C14.1, C42.2, L3.2, R5.1, U3.C2 (VOS), U8.1 (VCC), U8.5 (IN2); also elsewhere on the board
+VBAT: C2.1, C3.1, C13.1, C40.1, L1.2, U1.15 (SYS), U1.16 (SYS), U3.A2 (VIN), U3.B1 (EN), U3.C1 (VSEL1), U3.D1 (VSEL2), U3.D2 (VSEL3), U8.8 (IN1)
+VBUS: C4.1, C5.1, D1.1 (K), F1.2, R11.1, U1.1 (VBUS), U1.24 (VBUS)
+VREGN: C8.1, R1.1, R6.1, U1.22 (REGN)
+VRUN: R9.2, U8.6 (OUT2); also elsewhere on the board
+VSYS: C41.1, U8.7 (OUT1); also elsewhere on the board
/AUX/BATT_STAT: U1.4 (STAT); also elsewhere on the board
/BATT/BATT_I2C_INT: R5.2, U1.7 (~INT); also elsewhere on the board
/BATT/BATT_PD_CC1: J1.6; also elsewhere on the board
/BATT/BATT_PD_CC2: J1.5; also elsewhere on the board
/BATT/BATT_SR_N: C7.1, R21.1, U1.13 (BAT), U1.14 (BAT), U15.C2 (SRN)
/BATT/BATT_SR_P: C11.1, J2.1, R21.2, U15.C1 (SRP), U15.C3 (BAT)
/BATT/BATT_USB_D+: J1.7; also elsewhere on the board
/BATT/BATT_USB_D-: J1.8; also elsewhere on the board
/BATT/MCU_VBUS_SNS: C12.1, R11.2, R12.1; also elsewhere on the board
/BATT/PM_VEN: U8.4 (EN2); also elsewhere on the board
/BATT/SYS_I2C_SCL: U1.5 (SCL), U15.A3 (SCL); also elsewhere on the board
/BATT/SYS_I2C_SDA: U1.6 (SDA), U15.A2 (SDA); also elsewhere on the board
/BATT/SYS_VEN: U8.3 (EN1); also elsewhere on the board
GND: C1.2, C2.2, C3.2, C4.2, C5.2, C7.2, C8.2, C11.2, C12.2, C13.2, C14.2, C40.2, C41.2, C42.1, C51.2, D1.2 (A), J1.3, J1.4, J2.3, R7.1, R8.2, R12.2, R14.2, U1.17 (PGND), U1.18 (PGND), U1.25 (PGND), U3.B2 (GND), U8.2 (GND), U15.B2 (VSS); also elsewhere on the board
unnamed: C6.1, L1.1, U1.19 (SW), U1.20 (SW)
unnamed: F1.1, J1.1, J1.2
unnamed: J2.2, R6.2, R8.1, U1.11 (TS)
unnamed: C6.2, U1.21 (BTST)
unnamed: C1.1, U1.23 (PMID)
unnamed: R1.2, U1.2 (PSEL)
unnamed: R7.2, U1.9 (~CE)
unnamed: L3.1, U3.A1 (SW)
unnamed: R14.1, U15.B1 (BIN)
unnamed: R9.1, U15.A1 (GPOUT)
unnamed: C51.1, U15.B3 (VDD)

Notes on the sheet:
1uH 39mΩ
RT2=100kΩ
VT2(20°C)=68.5%VREGN
Iq=40uA
XH2.54-3P
VSYS: 200mA
BETA=3750
VLS201612HBX-2R2M-1
VT4(55°C)=34.5%VREGN
Iq=50uA
25V 0402
VT1(10°C)=73.5%VREGN
USB Type-C
XH1.25-8P
RT1=5.88kΩ
(BQ25601)
VT3(45°C)=45%VREGN
VALW: 100uA/4mA
R(10°C)=19.5kΩ
1206
R(55°C)=3.2kΩ
VBAT: 60uA/150uA
R(25°C)=10kΩ
I2C Address: 7'b1010011
SMF12A
VRUN: 250uA/40mA
Battery Pack

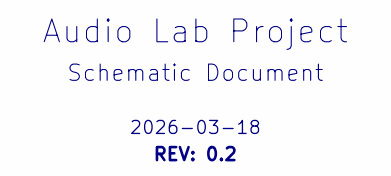
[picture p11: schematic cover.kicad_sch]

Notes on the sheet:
2026-03-18
Schematic Document
REV: 0.2
Audio Lab Project

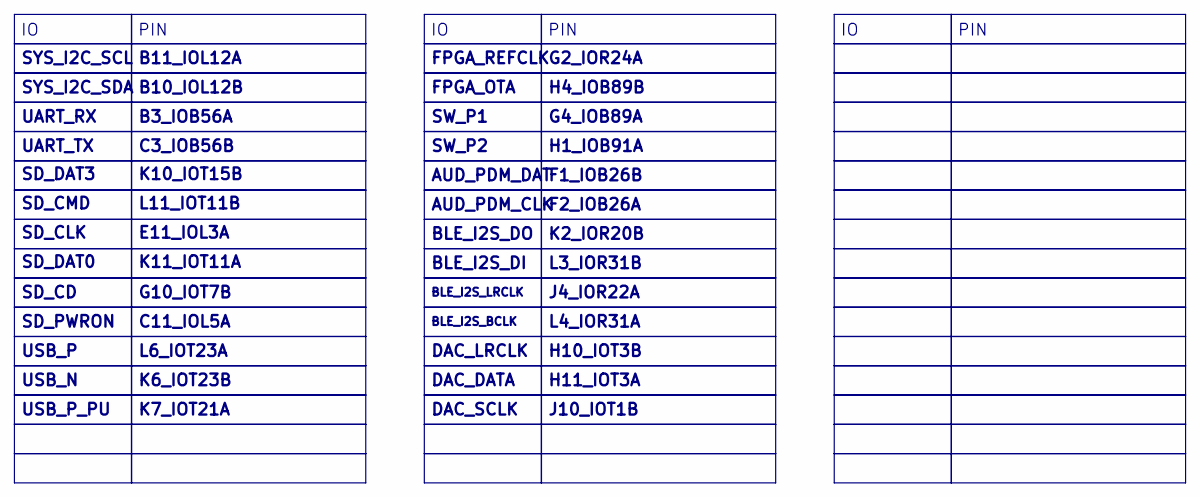
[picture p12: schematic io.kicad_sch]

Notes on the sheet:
L4_IOR31A
SD_PWRON
BLE_I2S_LRCLK
UART_RX
L6_IOT23A
SD_CD
AUD_PDM_DAT
SYS_I2C_SDA
K2_IOR20B
H10_IOT3B
J4_IOR22A
DAC_SCLK
G10_IOT7B
K6_IOT23B
SYS_I2C_SCL
E11_IOL3A
G2_IOR24A
G4_IOB89A
C3_IOB56B
K10_IOT15B
DAC_LRCLK
K7_IOT21A
USB_P
DAC_DATA
L3_IOR31B
BLE_I2S_DO
FPGA_OTA
PIN
L11_IOT11B
K11_IOT11A
F1_IOB26B
B3_IOB56A
BLE_I2S_BCLK
B10_IOL12B
UART_TX
H11_IOT3A
SD_CMD
SD_DAT0
USB_N
C11_IOL5A

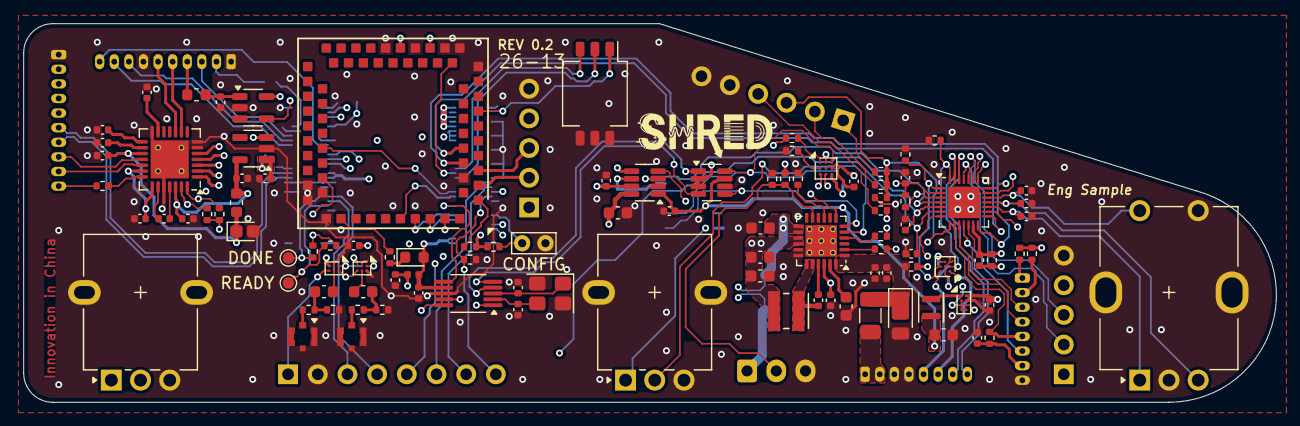
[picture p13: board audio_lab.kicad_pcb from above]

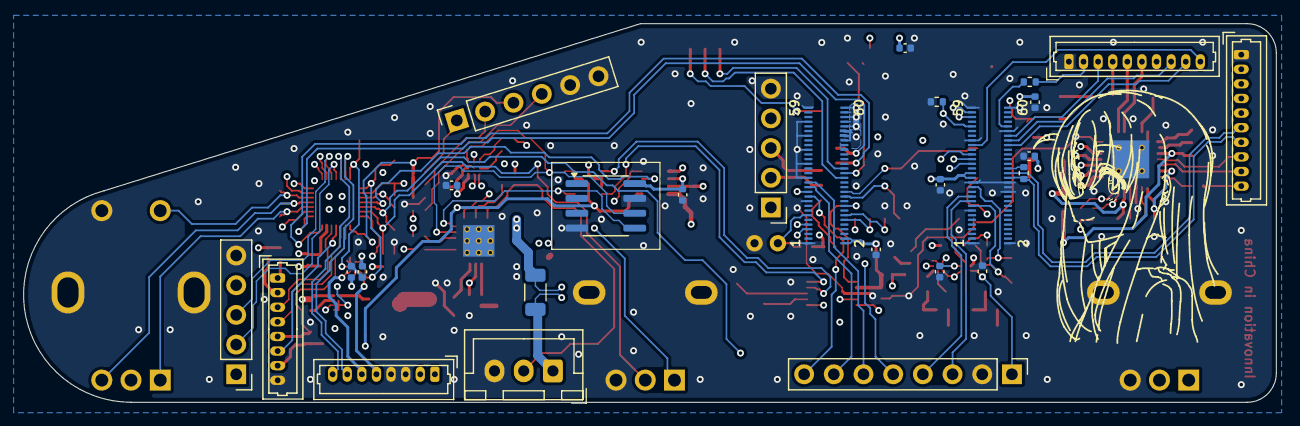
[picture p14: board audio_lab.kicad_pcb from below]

Board: 4 copper layers, 107.2 x 32.4 mm, 131 parts (27 on the bottom side), 126 nets.

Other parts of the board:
CONFIG: TestPoint_2Pole; TestPoint_Bridge_Pitch2.0mm_Drill0.7mm
DONE: TestPoint; TestPoint_Pad_D1.0mm
READY: TestPoint; TestPoint_Pad_D1.0mm

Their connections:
/FPGA/D7_DONE: DONE.1; also elsewhere on the board
/FPGA/D8_RECONFIG: CONFIG.1; also elsewhere on the board
/FPGA/E8_READY: READY.1; also elsewhere on the board
GND: CONFIG.2; also elsewhere on the board

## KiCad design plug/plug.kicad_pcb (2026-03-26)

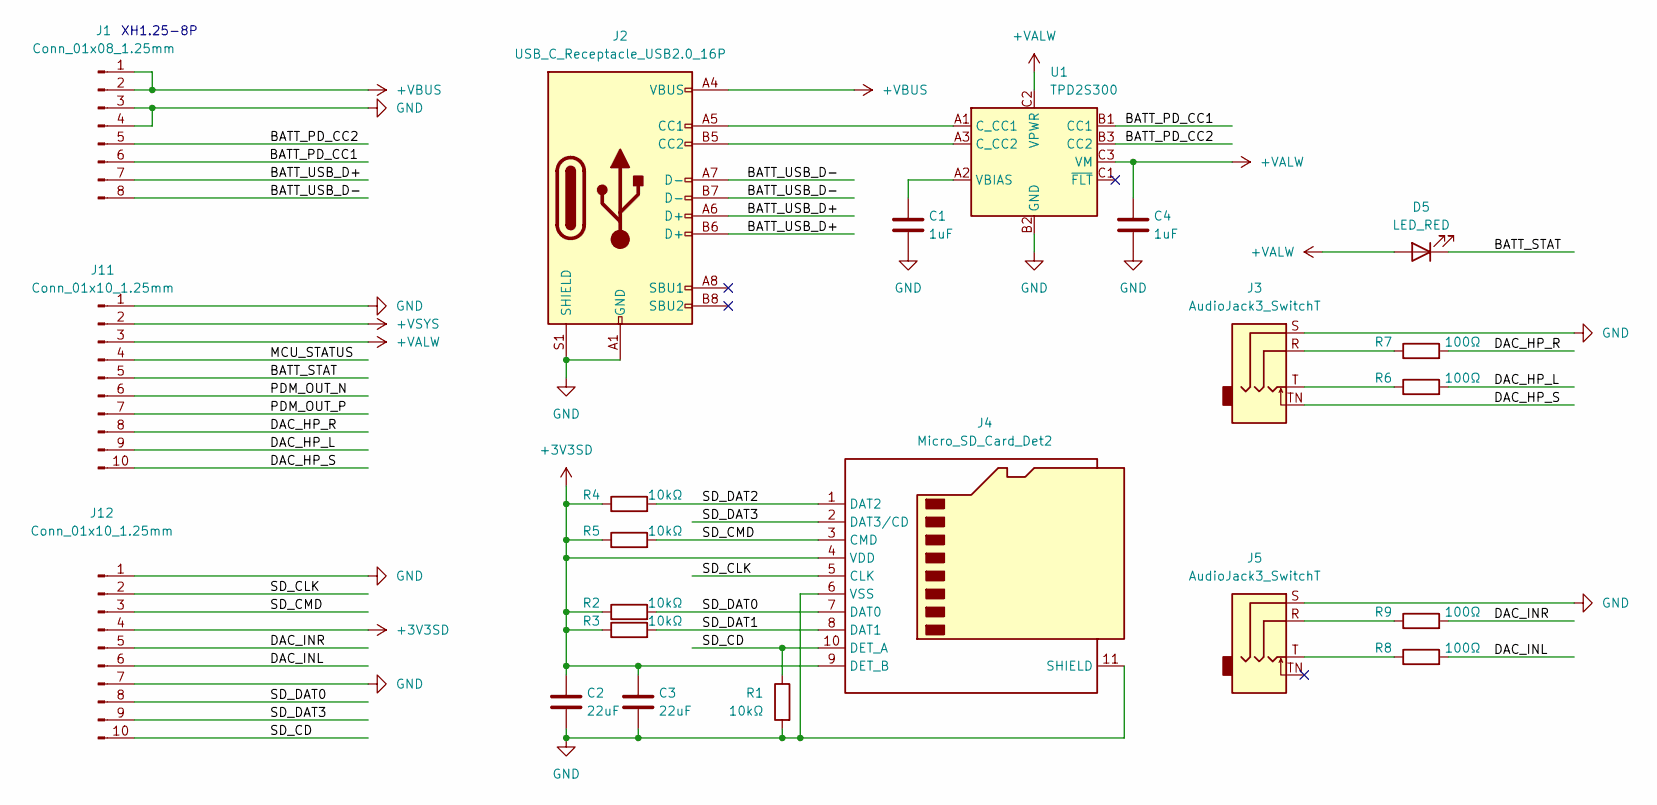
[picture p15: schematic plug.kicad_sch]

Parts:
C1, C4: 1uF; C_0402_1005Metric
C2, C3: 22uF; C_0603_1608Metric
D5: LED_RED; D_0603_1608Metric
J1: Conn_01x08_1.25mm; Molex_PicoBlade_53047-0810_1x08_P1.25mm_Vertical
J2: USB_C_Receptacle_USB2.0_16P; USB_C_Receptacle_XKB_U262-16XN-4BVC11
J3, J5: AudioJack3_SwitchT; Jack_3.5mm_KoreanHropartsElec_PJ-327D-5A_Horizontal
J4: Micro_SD_Card_Det2; microSD_HC_Molex_104031-0811
J11, J12: Conn_01x10_1.25mm; Molex_PicoBlade_53047-1010_1x10_P1.25mm_Vertical
R1, R2, R3, R4, R5: 10kΩ; R_0402_1005Metric
R6, R7, R8, R9: 100Ω; R_0402_1005Metric
U1: TPD2S300; Texas_DSBGA-9_1.36x1.36mm_Layout3x3_P0.4mm

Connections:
+3V3SD: C2.1, C3.1, J4.4 (VDD), J4.9 (DET_B), J12.4, R2.1, R3.1, R4.1, R5.1
+VALW: C4.1, D5.2 (A), J11.3, U1.C2 (VPWR), U1.C3 (VM)
+VBUS: J1.1, J1.2, J2.A4 (VBUS), J2.A9 (VBUS), J2.B4 (VBUS), J2.B9 (VBUS)
+VSYS: J11.2
/BATT_PD_CC1: J1.6, U1.B1 (CC1)
/BATT_PD_CC2: J1.5, U1.B3 (CC2)
/BATT_STAT: D5.1 (K), J11.5
/BATT_USB_D+: J1.7, J2.A6 (D+), J2.B6 (D+)
/BATT_USB_D-: J1.8, J2.A7 (D-), J2.B7 (D-)
/DAC_HP_L: J11.9, R6.2
/DAC_HP_R: J11.8, R7.2
/DAC_HP_S: J3.TN, J11.10
/DAC_INL: J12.6, R8.2
/DAC_INR: J12.5, R9.2
/MCU_STATUS: J11.4
/PDM_OUT_N: J11.6
/PDM_OUT_P: J11.7
/SD_CD: J4.10 (DET_A), J12.10, R1.1
/SD_CLK: J4.5 (CLK), J12.2
/SD_CMD: J4.3 (CMD), J12.3, R5.2
/SD_DAT0: J4.7 (DAT0), J12.8, R2.2
/SD_DAT1: J4.8 (DAT1), R3.2
/SD_DAT2: J4.1 (DAT2), R4.2
/SD_DAT3: J4.2 (DAT3/CD), J12.9
GND: C1.2, C2.2, C3.2, C4.2, J1.3, J1.4, J2.A1 (GND), J2.A12 (GND), J2.B1 (GND), J2.B12 (GND), J2.S1 (SHIELD), J3.S, J4.6 (VSS), J4.11 (SHIELD), J5.S, J11.1, J12.1, J12.7, R1.2, U1.B2 (GND); also elsewhere on the board
unnamed: J2.A5 (CC1), U1.A1 (C_CC1)
unnamed: J2.B5 (CC2), U1.A3 (C_CC2)
unnamed: J3.R, R7.1
unnamed: J3.T, R6.1
unnamed: J5.R, R9.1
unnamed: J5.T, R8.1
unnamed: C1.1, U1.A2 (VBIAS)

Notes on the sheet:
XH1.25-8P

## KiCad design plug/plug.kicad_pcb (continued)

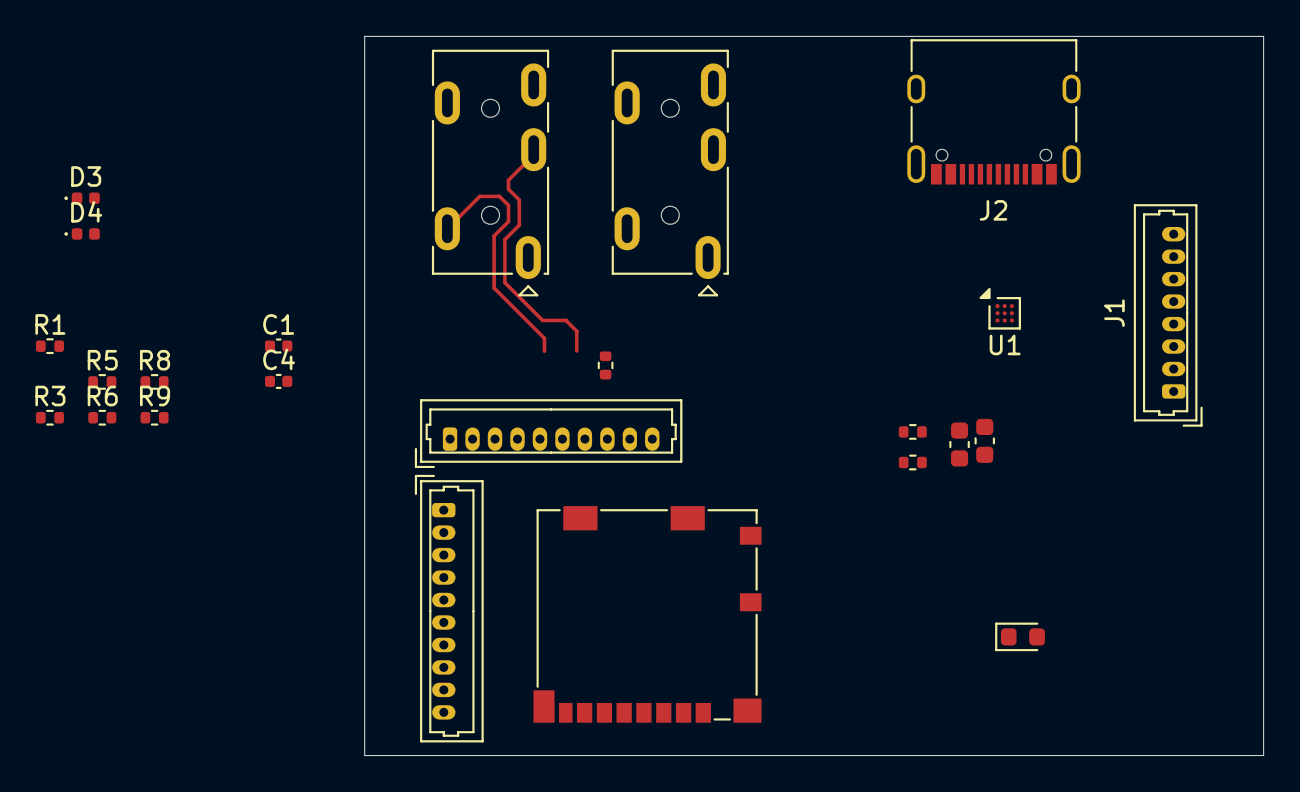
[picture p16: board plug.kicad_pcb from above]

Board: 2 copper layers, 50.0 x 40.0 mm, 24 parts (0 on the bottom side), 28 nets.

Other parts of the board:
D3, D4: D_TVS; D_0402_1005Metric

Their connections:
GND: D3.1 (A1), D4.1 (A1); also elsewhere on the board
